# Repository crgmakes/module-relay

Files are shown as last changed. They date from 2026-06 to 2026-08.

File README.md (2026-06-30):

# Relay Module

All the source files for the relay module hardware.

# Software 

You will need [KiCad](https://kicad.org) to view and edit this design. Click [here](https://www.kicad.org/download/) to download.

You will also need all the associated libraries and models to drive the design if you want to make changes or view the 3D rendering:

https://github.com/crgmakes/kicad-library.git

Kicad MUST be configured properly to use all the files in this repo. Once you have Kicad installed, under Preferences->Configure Paths..., make the following entries:

1 - KICAD_USER_DIR -> set to the root location of where you placed the above repository.
2 - KICAD_USER_LIBRARY = ${KICAD_USER_DIR}/Library
3 - KICAD_USER_MODEL_DIR = ${KICAD_USER_LIBRARY}/models
4 - KICAD_USER_TEMPLATE_DIR	= ${KICAD_USER_LIBRARY}/templates	

Kicad will operate mostly normally if these are not set properly. You will notice an issue when you view the PCB in 3D mode.

***NOTE***: after makeing a release build in git, if your rendered 3D images are missing components, ensure the path to EVERY component model is set to ${KICAD_USER_MODEL_DIR}/<model name>.

Kicad sometimes replaces the variable with an expansion and that FAILS during the build process because the expanded variable is local and does not match the build environment.

---

THE DESIGN IS PROVIDED "AS IS" AND THE AUTHOR DISCLAIMS ALL WARRANTIES WITH REGARD TO THIS DESIGN INCLUDING ALL IMPLIED WARRANTIES OF MERCHANTABILITY AND FITNESS. IN NO EVENT SHALL THE AUTHOR BE LIABLE FOR ANY SPECIAL, DIRECT, INDIRECT, OR CONSEQUENTIAL DAMAGES OR ANY DAMAGES WHATSOEVER RESULTING FROM LOSS OF USE, DATA OR PROFITS, WHETHER IN AN ACTION OF CONTRACT, NEGLIGENCE OR OTHER TORTIOUS ACTION, ARISING OUT OF OR IN CONNECTION WITH THE USE OR PERFORMANCE OF THIS DESIGN.

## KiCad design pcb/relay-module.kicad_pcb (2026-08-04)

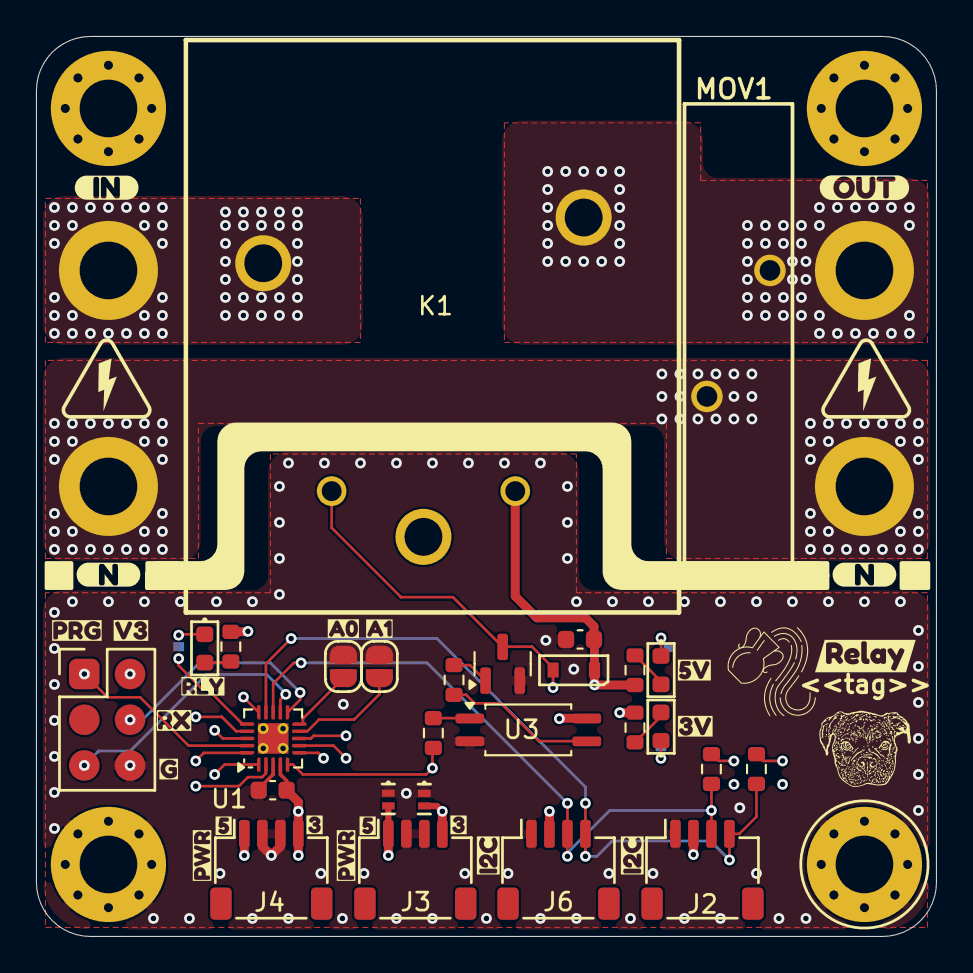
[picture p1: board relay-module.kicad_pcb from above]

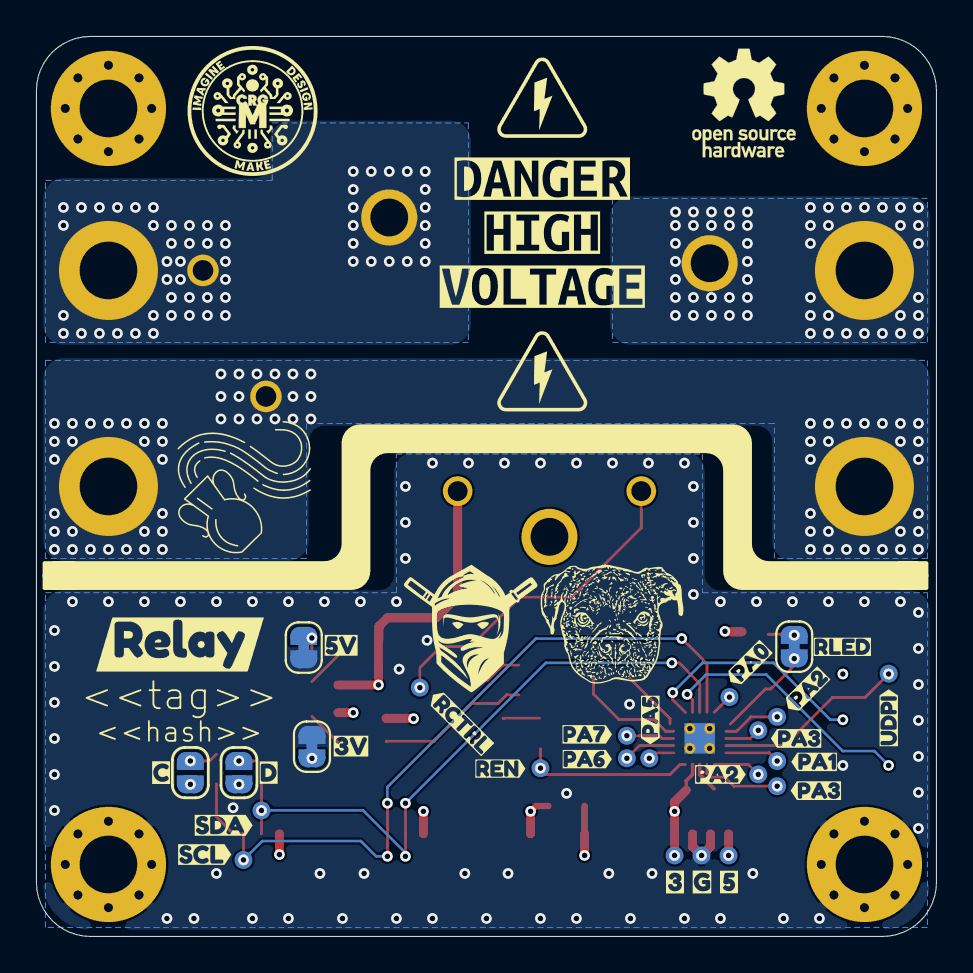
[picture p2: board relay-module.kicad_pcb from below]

Board: 4 copper layers, 50.0 x 50.0 mm, 116 parts (55 on the bottom side), 36 nets.

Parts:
C1, C2: 0.1uF; C_0603_1608Metric
D1: BAT48JFILM; SOD-323
D2, D3: Orange; LED_0603_1608Metric
D5: Red; LED_0603_1608Metric
D6: PESD5V5C1BL; DFN1006-2
D7: PESD3V3S1BL; DFN1006-2
H1, H2, H3, H4: MountingHole; MountingHole_3.2mm_M3_Pad_Via
J1: AVR-UPDI-UART-6; PinHeader_2x03_P2.54mm_Vertical_SMD
J2, J3, J4, J6: JST_SH_SM04B-SRSS-TB_1x04-1MP_P1.00mm_Horizontal
JP1, JP4, JP6: SolderJumper-2_P1.3mm_Bridged_RoundedPad1.0x1.5mm
JP2, JP3, JP7, JP8: SolderJumper-2_P1.3mm_Open_RoundedPad1.0x1.5mm
K1: PR24-5V-900-1A; RELAY_PR24-5V-900-1A
LOGO1: Aquarius Logo 8mm
LOGO2: CRGM Logo 7mm
LOGO3: Aquarius Logo 5mm
LOGO4: Roxy 5mm
LOGO5: OSHW-Logo_5.7x6mm_SilkScreen
LOGO6: Roxy 8mm
LOGO7: FNWW Face 8mm
MOV1: V250LA40BP
P1, P2, P3, P4: MountingHole_Pad; MountingHole_3.2mm_M3_ISO14580_Pad
Q1: MMBT3904; SOT-23
R1, R2: 220; R_0603_1608Metric
R3, R4, R12: 4.7K; R_0603_1608Metric
R7: 1k; R_0603_1608Metric
R15: 1K; R_0603_1608Metric
S1, S2, S3, S4: HIGH-VOLTAGE-5MM
TP1, TP2, TP3, TP6, TP7, TP8, TP9, TP10, TP11, TP12, TP13, TP14, TP15, TP16, TP20, TP21, TP22: TestPoint_Pad_D1.0mm
U1: ATtiny1616-MNR; VQFN-20-1EP_3x3mm_P0.4mm_EP1.7x1.7mm_ThermalVias
U3: TLP291; SOIC-4_4.55x2.6mm_P1.27mm
kibuzzard-67E371A7: G***; kibuzzard-67E371A7
kibuzzard-67E3720C, kibuzzard-67E3720C#2: G***; kibuzzard-67E3720C
kibuzzard-67E37192: G***; kibuzzard-67E37192
kibuzzard-68F5AC52: G***; kibuzzard-68F5AC52
kibuzzard-68F58F7A: G***; kibuzzard-68F58F7A
kibuzzard-68F58FDE: G***; kibuzzard-68F58FDE
kibuzzard-68F58FEF: G***; kibuzzard-68F58FEF
kibuzzard-68F595B8: G***; kibuzzard-68F595B8
kibuzzard-690A2BAF: G***; kibuzzard-690A2BAF
kibuzzard-690A2BB5: G***; kibuzzard-690A2BB5
kibuzzard-690A7DBB: G***; kibuzzard-690A7DBB
kibuzzard-690A7DC5: G***; kibuzzard-690A7DC5
kibuzzard-6918F9A4: G***; kibuzzard-6918F9A4
kibuzzard-6918FB8A: G***; kibuzzard-6918FB8A
kibuzzard-6918FB91: G***; kibuzzard-6918FB91
kibuzzard-69092EA7: G***; kibuzzard-69092EA7
kibuzzard-69092EAF: G***; kibuzzard-69092EAF
kibuzzard-69782BCF: G***; kibuzzard-69782BCF
kibuzzard-69782BD8: G***; kibuzzard-69782BD8
kibuzzard-690926DB: G***; kibuzzard-690926DB
kibuzzard-690932B6: G***; kibuzzard-690932B6
kibuzzard-690932D2: G***; kibuzzard-690932D2
kibuzzard-690932EF: G***; kibuzzard-690932EF
kibuzzard-690933B9: G***; kibuzzard-690933B9
kibuzzard-690933C6: G***; kibuzzard-690933C6
kibuzzard-690933D0: G***; kibuzzard-690933D0
kibuzzard-697827C3: G***; kibuzzard-697827C3
kibuzzard-697827D2: G***; kibuzzard-697827D2
kibuzzard-697827F7: G***; kibuzzard-697827F7
kibuzzard-697830E3, kibuzzard-697830E3#2: G***; kibuzzard-697830E3
kibuzzard-697831DA, kibuzzard-697831DA#2: G***; kibuzzard-697831DA
kibuzzard-6909280B: G***; kibuzzard-6909280B
kibuzzard-6978378C: G***; kibuzzard-6978378C
kibuzzard-69092782: G***; kibuzzard-69092782
kibuzzard-69092816: G***; kibuzzard-69092816
kibuzzard-69093282: G***; kibuzzard-69093282
kibuzzard-69093358: G***; kibuzzard-69093358
kibuzzard-69093373: G***; kibuzzard-69093373
kibuzzard-69093383: G***; kibuzzard-69093383
kibuzzard-69093389: G***; kibuzzard-69093389
kibuzzard-69093390: G***; kibuzzard-69093390
kibuzzard-69093403: G***; kibuzzard-69093403
kibuzzard-69179320: G***; kibuzzard-69179320
kibuzzard-69179327: G***; kibuzzard-69179327
kibuzzard-69179334: G***; kibuzzard-69179334

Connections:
+3.3V: C1.1, D7.2 (K2), J1.2 (VCC), J2.2, J3.4 (V3.3), J4.4 (V3.3), J6.2, JP7.2 (B), JP8.2 (B), R7.1, R15.1, TP21.1 (1_1), U1.4 (VCC), U3.4
+5V: C2.1, D1.1 (K), D6.2 (K2), J3.1 (V5), J4.1 (V5), K1.A1 (COIL1), R12.1, TP20.1 (1_1)
/MCU/A0: JP2.2 (B), U1.10 (PB4/0OUT)
/MCU/A1: JP3.2 (B), U1.9 (PB5/CLK0)
/MCU/PA1: TP8.1 (1_1), U1.20 (MOSI/PA1)
/MCU/PA2: TP9.1 (1_1), U1.1 (MISO/PA2)
/MCU/PA3: TP10.1 (1_1), U1.2 (SCK/PA3)
/MCU/PA5: TP12.1 (1_1), U1.6 (VREF/PA5)
/MCU/PA6: TP13.1 (1_1), U1.7 (DAC/PA6)
/MCU/PA7: TP14.1 (1_1), U1.8 (1OUT/PA7)
/MCU/PC0: TP11.1 (1_1), U1.15 (PC0/SCLK)
/MCU/PC2: TP6.1 (1_1), U1.17 (PC2)
/MCU/PC3: TP7.1 (1_1), U1.18 (PC3)
/Power/V3.3LED: D2.2 (A), R15.2
/Power/V5LED: D3.2 (A), R12.2
/Relay/LOAD_IN: K1.COM1, P3.1 (1_1)
/Relay/LOAD_OUT: K1.NO, MOV1.P$1, P4.1 (1_1)
/Relay/NEUTRAL: MOV1.P$2, P1.1 (1_1), P2.1 (1_1)
/Relay/RELAY_CTRL: D1.2 (A), K1.A2 (COIL2), Q1.3 (C), TP1.1 (1_1)
GND: C1.2, C2.2, D6.1 (K1), D7.1 (K1), H1.1 (1_1), H2.1 (1_1), J1.6 (GND), J2.1, J3.2 (GND), J3.3 (GND), J4.2 (GND), J4.3 (GND), J6.1, JP1.1 (A), JP2.1 (A), JP3.1 (A), JP4.1 (A), Q1.2 (E), TP22.1 (1_1), U1.3 (GND), U1.21 (GND), U3.2
unnamed: D2.1 (K), JP4.2 (B)
unnamed: D3.1 (K), JP1.2 (B)
unnamed: D5.2 (A), R7.2
unnamed: D5.1 (K), JP6.2 (B)
unnamed: JP7.1 (A), R4.2
unnamed: JP8.1 (A), R3.2
unnamed: Q1.1 (B), R2.2
unnamed: R1.2, U3.1
unnamed: R2.1, U3.3
RELAY_EN: R1.1, TP2.1 (1_1), U1.5 (~SS/PA4)
RELAY_LED: JP6.1 (A), U1.16 (PC1)
RXD: J1.4 (RXD), U1.11 (PB3/RxD)
SCL: J2.4, J6.4, R3.1, TP15.1 (1_1), U1.14 (PB0/SCL)
SDA: J2.3, J6.3, R4.1, TP16.1 (1_1), U1.13 (PB1/SDA)
TXD: J1.5 (TXD), U1.12 (PB2/TxD)
UPDI: J1.1 (DATA), TP3.1 (1_1), U1.19 (UPDI/PA0)

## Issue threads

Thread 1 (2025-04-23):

Add test points to critical signals

cyberreefguru, 2025-04-23:
Add test points to RELAY_CONTROL, UPDI, RELAY_CTRL, 5V, 3.3V, GND.

cyberreefguru, 2025-05-14:
Added test points; moved test points to bottom

Closed 2025-05-14.

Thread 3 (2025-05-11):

Add power LED to indicate power is received

cyberreefguru, 2025-05-11:
Add power LED to indicate power is received. One LED for 3.3 and one for 5v.

cyberreefguru, 2025-05-14:
added LED for v5 and v3.3

Closed 2025-05-14.

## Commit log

2025-03-26 Initial checking.
    [i2c_interface.kicad_sch, power.kicad_sch, relay-module.kicad_pcb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]
2025-03-26 initial checkin
    [power.kicad_sch, relay-module.kicad_pcb, relay-module.kicad_sch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]
2025-04-11 Updated silkscreen
    [relay-module.kicad_pcb, relay-module.kicad_sch]
2025-04-23 v1.0 Relay Module Panel 2x2
    [bom.csv, designators.csv, positions.csv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]
2025-04-23 removed unnecessary files.
    [i2c_interface.kicad_sch, power.kicad_sch]
2025-04-29 Updated for panelization.
    [relay-module.kicad_pcb, relay-module.kicad_sch]
2025-05-12 Added power, relay LEDs
    [relay-module.kicad_pcb, relay-module.kicad_sch]
2025-05-14 Changed 5v to orange LED
    [relay-module.kicad_pcb, relay-module.kicad_sch]
2025-06-09 Refined relay based testing
    [relay-module.kicad_pcb, relay-module.kicad_sch]
2025-06-12 Added CI files; deleted unnecessary files
    [bom.csv, designators.csv, positions.csv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]
2025-06-12 Fixed missing LCSC part numbers; updated CI script
    [relay-module.kicad_pcb, relay-module.kicad_sch]
2025-06-21 Rerouted after adding test points
    Added test points to all pins
    Added serial connector
    Added relay LED
    Changed symbols and footprints to CRGM
    Moved pins around to optimize routing
    [relay-module.kicad_pcb, relay-module.kicad_sch]
2025-06-21 schematic and PCB clean up
    [relay-module.kicad_pcb, relay-module.kicad_sch]
2025-06-21 Updated mounting holes; rounded corners
    [relay-module.kicad_pcb, relay-module.kicad_sch]
2025-06-22 Changed to multi-sheet
    [interface.kicad_sch, mcu.kicad_sch, relay-module.kicad_pcb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]
2025-06-26 Updated frame template
    [interface.kicad_sch, mcu.kicad_sch, relay-module.kicad_pcb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]
2025-06-27 Updated worksheet template
    [interface.kicad_sch, mcu.kicad_sch, relay-module.kicad_pcb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]
2025-06-27 Updated worksheet template and logo
    [relay-module.kicad_pcb, relay-module.kicad_sch]
2025-07-13 Update PCB layer colors and add requirements text box
    Specified silk screen and solder mask colors in relay-module.kicad_pcb and updated the 3D model path. Added a detailed PCB requirements text box to requirements.kicad_sch. Updated embedded image data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
    [relay-module.kicad_pcb, relay-module.kicad_sch, requirements.kicad_sch]
2025-09-22 Fixed model path
    [relay-module.kicad_pcb]
2025-10-21 Updated to latest libraries
    Changed to all CRG footprints (mostly)
    Moved somethings around
    Added LED jumper
    Updated symbols/logos
    [interface.kicad_sch, mcu.kicad_sch, relay-module.kicad_pcb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]
2025-10-27 Fixed capacitor attributes
    [interface.kicad_sch, mcu.kicad_sch, relay-module.kicad_pcb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]
2025-11-03 Updated for consistency
    Updated footprints
    Added ESD to power
    Added second QWICC connector
    Rerouted as required
    Made mounting holes grounded
    [interface.kicad_sch, mcu.kicad_sch, power.kicad_sch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]
2025-11-04 Updated parts and models
    [relay-module.kicad_pcb, requirements.kicad_sch]
2025-11-04 Updated panel options
    Hide symbol value
    Removed old 2x2 panel options
    [relay-module.kicad_pcb, requirements.kicad_sch]
2025-11-05 Updated for DFM
    [relay-module.kicad_pcb]
2025-11-07 final clean up and processing
    [relay-module.kicad_pcb]
2025-11-16 Updated for DFM
    Updated board stack up - 2oz/1oz copper
    Move components around to add stitching vias
    Updated render in schematics
    [relay-module.kicad_pcb, relay-module.kicad_sch]
2025-11-17 Updated silkscreen, zones, and stitching vias
    [relay-module.kicad_pcb]
2025-12-28 Updated I2C pulls to open jumper
    Fixed I2C to be open rather than bridged.
    Changed opto-isolator to CRGM library.
    Updated picture of bottom side to match new footprint
    [interface.kicad_sch, mcu.kicad_sch, power.kicad_sch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]
2026-02-03 Updated for consistency with new patterns
    [interface.kicad_sch, mcu.kicad_sch, power.kicad_sch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]
2026-02-18 Silkscreen improvements
    [relay-module.kicad_pcb]
2026-03-01 replaced .wrl with .step
    [relay-module.kicad_pcb]
2026-08-04 Changed opto to be a little smaller
    Updated to v10
    [interface.kicad_sch, mcu.kicad_sch, power.kicad_sch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]
